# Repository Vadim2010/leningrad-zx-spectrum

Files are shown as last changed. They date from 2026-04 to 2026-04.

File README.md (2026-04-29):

# ZX Spectrum "Leningrad" Clone  
### Educational & Configurable Hardware Platform

---

## Overview

This repository is dedicated to the legendary **ZX Spectrum "Leningrad"**, one of the most widespread Soviet clones of the original [ZX Spectrum](https://en.wikipedia.org/wiki/ZX_Spectrum).

The project contains:
- The **original schematic** of the first "Leningrad" revision  
- A **modified, configurable version** of the board designed as an educational platform  

The goal is not just preservation, but **understanding** - how the machine works, why certain issues occur, and how historical fixes evolved.

---

## 🖼️ Hardware Preview

### Bare PCB

<p align="center">
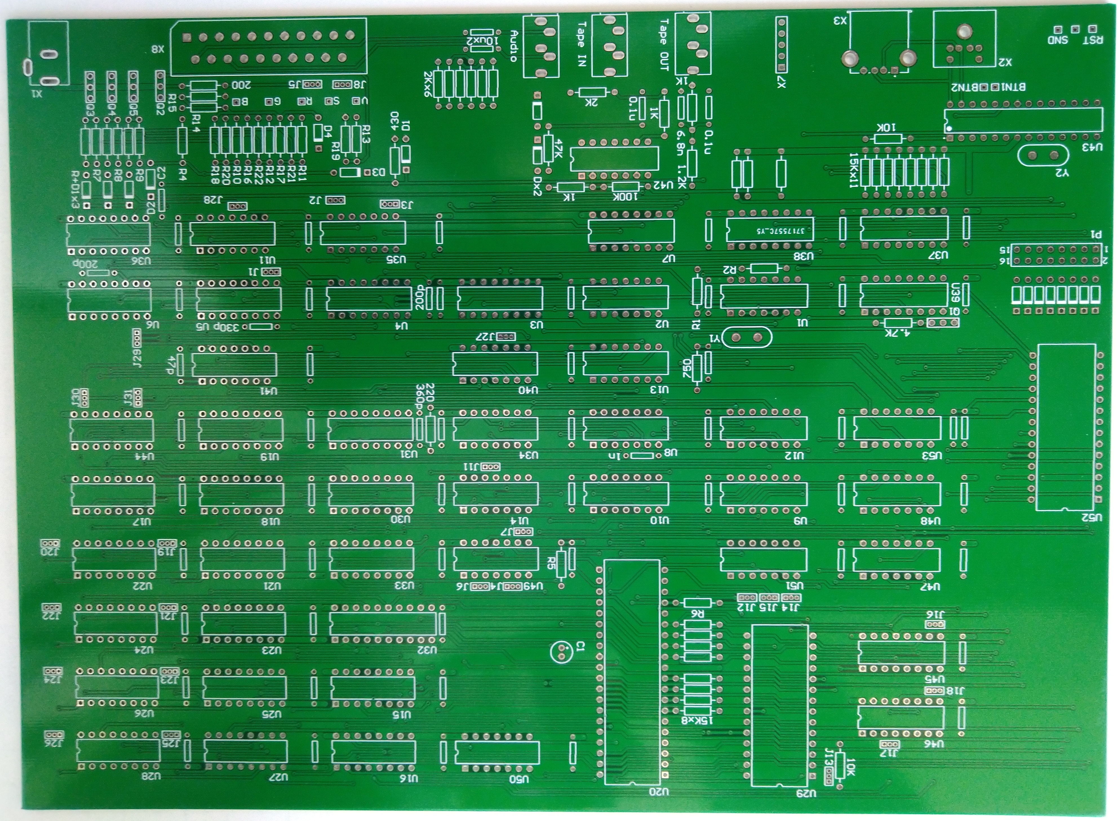
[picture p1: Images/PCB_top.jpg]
PCB top
  
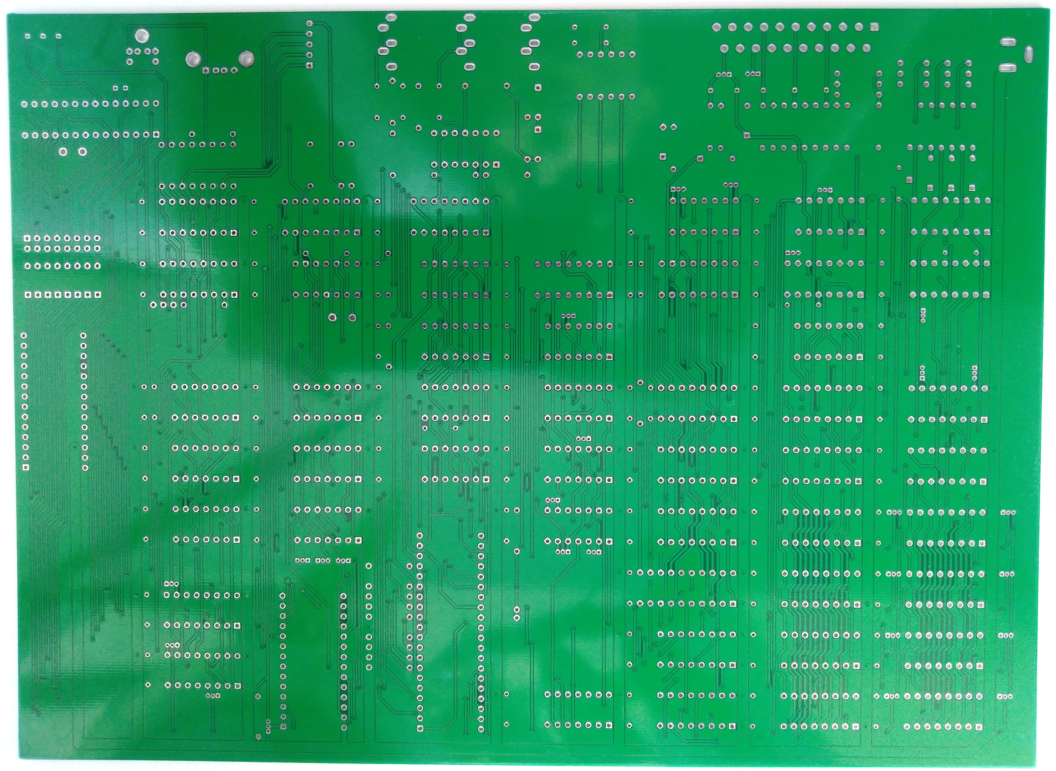
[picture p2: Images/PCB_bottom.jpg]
PCB bottom
  
</p>

### Assembled Board

<p align="center">
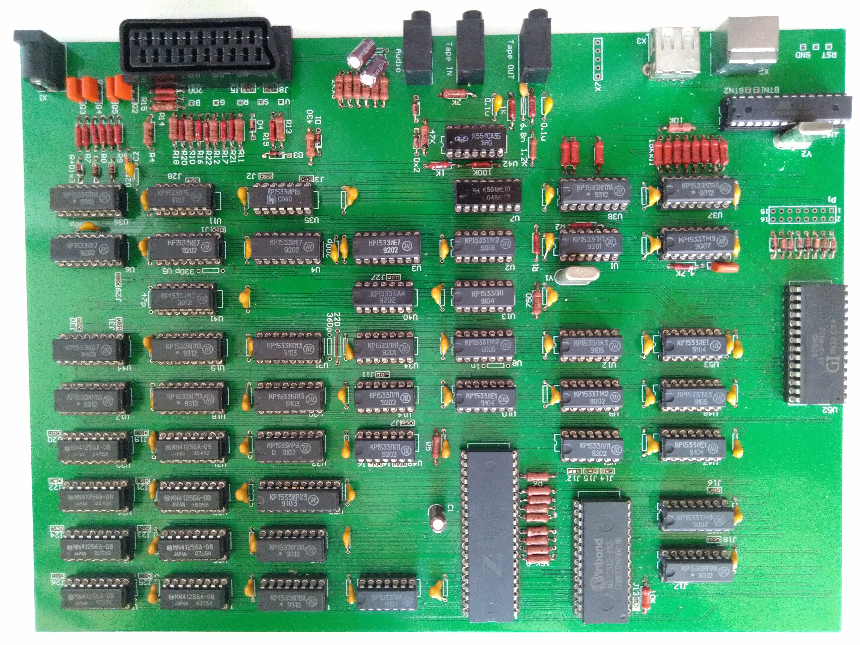
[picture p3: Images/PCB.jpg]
Assembled board
  
</p>

---

## A Brief History

The original [ZX Spectrum](https://en.wikipedia.org/wiki/ZX_Spectrum) was developed in the early 1980s by [Sir Clive Sinclair](https://en.wikipedia.org/wiki/Clive_Sinclair) and his company [Sinclair Research](https://en.wikipedia.org/wiki/Sinclair_Research). It became one of the most influential home computers of its time, shaping an entire generation of developers and enthusiasts.

Due to limited availability of Western hardware in many countries — especially in the USSR and Eastern Europe — a wide ecosystem of **unofficial clones** emerged. These ranged from near-identical reproductions to heavily modified designs adapted to locally available components.

Among them, the **"Leningrad"** clone became one of the most popular due to its:
- Relative simplicity  
- Component accessibility  
- Reliability (for its time)  

This repository pays respect to the original creators, the community that kept the platform alive, and everyone who contributed improvements over the decades.

---

## Project Goals

- Preserve the **original Leningrad schematic**
- Provide a **modernized, flexible board design**
- Enable **hands-on learning** of hardware behavior
- Demonstrate **real-world faults and fixes**
- Avoid destructive modifications (no cutting traces or solder hacks)

---

## Educational Concept

The modified board introduces a **jumper-based configuration system**.

By changing jumper positions, you can:

- Recreate the **original unmodified board**
- Apply **selected historical fixes**
- Mix different modifications
- Intentionally reproduce known hardware issues

This allows you to **observe cause and effect directly**, which is extremely valuable for learning.

---

## What You Can Study

- Timing issues and signal integrity  
- Memory contention behavior  
- Video signal stability  
- Bus conflicts and decoding quirks  

All of these can be observed:
- On a **TV/display output**
- With an **oscilloscope** (recommended for deeper analysis)

---

## Repository Structure

```
leningrad-zx-spectrum/
  ├── Leningrad/
  └── Leningrad_mod/
```

Leningrad       - Original Leningrad schematic and PCB (Altium)
Leningrad_mod   - Configurable board design (Altium)

---

## Hardware Features (Modified Version)

- Jumper-selectable logic paths  
- Support for multiple known fixes  
- Non-destructive experimentation  
- Designed for repeatable testing scenarios  

---

## Example Use Cases

- Compare **original vs fixed video timing**
- Demonstrate **typical hardware faults**
- Teach **digital electronics fundamentals**
- Explore **historical engineering decisions**

---

## ⚙️ Jumper Configuration Matrix

This board uses a fully jumper-based configuration system, allowing reconstruction of multiple hardware variants of the **ZX Spectrum "Leningrad"** architecture.

---

### ⏱ System Clock (Quartz Configuration)

| Quartz MHz | J1  | J2  | J3  |
|---|-----|-----|-----|
| 12.5 | 1-2 | 1-2 | 1-2 |
| 13.0 | 2-3 | 1-2 | 1-2 |
| 13.5 | 1-2 | 2-3 | 1-2 |
| 14.0 | 2-3 | 2-3 | 1-2 |
| 14.5 | 1-2 | 1-2 | 2-3 |
| 15.0 | 2-3 | 1-2 | 2-3 |
| 15.5 | 1-2 | 2-3 | 2-3 |
| 16.0 | 2-3 | 2-3 | 2-3 |

---

### 🧠 RAM Configuration

| Mode | J4  | J6  | J7  | J12–J26 |
|---|-----|-----|-----|---|
| 48K  | 1-2 | 1-2 | 1-2 | 1-2 |
| 128K | 2-3 | 2-3 | 2-3 | 2-3 |
| 256K | 2-3 | 2-3 | 1-2 | 2-3 |

> Enables switching between different memory architectures without PCB modification.

---

### 🎨 Video Output Mode

| Mode | J5  | J8  |
|---|-----|-----|
| RGB | 1-2 | 1-2 |
| Composite | 2-3 | 2-3 |

---

### 🔧 Logic IC Configuration

| IC Type | J11 |
|---|-----|
| SN74ALS373N | 1-2 |
| SN74ALS374N | 2-3 |

---

### 📺 Video Signal Enhancements

| Mode | J27–J30 |
|---|---|
| Leningrad | 1-2 |
|  Improve  | 2-3 |

---

### ⚡ Interrupt Handling

| Mode | J31 |
|---|-----|
| Leningrad | 1-2 |
|  Improve  | 2-3 |

---

## 🧪 Design Philosophy

This system is designed for **non-destructive hardware experimentation**:

- No trace cutting required  
- No permanent modifications  
- Full restoration of original behavior possible  

Simply change jumper positions to switch between configurations.

---

## Acknowledgements

Special thanks to:
- Sir Clive Sinclair for the original concept  
- Sinclair Research for the ZX Spectrum platform  
- The global retro computing community  
- Contributors who developed and documented hardware fixes over the years  

---

## Contributing

Contributions are welcome:
- Additional fixes  
- Measurements and oscilloscope captures  
- Documentation improvements  
- Historical research  

---

## Final Notes

This project is as much about **history** as it is about **engineering**.

It’s a way to explore how constraints, creativity, and community-driven innovation shaped one of the most iconic 8-bit ecosystems.

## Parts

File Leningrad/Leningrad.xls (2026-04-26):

Designator | LibRef | Quantity | Comment
ICs
U1, U34 | SN74LS04N | 2 | Orig K555LN1
U2, U8, U9 | SN74LS74N | 3 | Orig K555TM2
U3, U4, U5, U6 | SN74LS193N | 4 | Orig K555IE7
U7 | MC14520A | HEF4520B | CD4520B | 1 | Orig K561IE10
U10 | SN74LS02N | 1 | Orig K555LE1
U11 | SN74LS86N | 1 | Orig K555LP5
U12 | SN74LS00N | 1 | Orig K555LA3
U13 | SN74LS08N | 1 | Orig K555LI1
U14 | SN74LS32N | 1 | Orig K555LL1
U15, U16, U17, U18, U19, U36, U37, U38 | SN74LS257N | 8 | Orig K555KP11
U20 | Z84C0010PEC | 1 | Z80
U21, U22, U23, U24, U25, U26, U27, U28 | MK4164 | TMM4164 | MCM6664 | 8 | Orig K565RU5G
U29, U41 | 2764 | СМ7764 | M2764A | 2 | Orig K573RF4 | K573RF6
U30, U31 | SN74LS298N | 2 | Orig K555KP13
U32 | SN74LS373N | 1 | Orig K555IR22
U33 | SN74LS165N | 1 | Orig K555IR9
U35 | SN74LS295N | 1 | Orig K555IR16
U39 | SN74LS174N | 1 | Orig K555ТМ9
U40 | SN74LS10N | 1 | Orig K555LA4
Resistors
R1, R3, R16 | 430 | 3
R2, R14 | 750 | 2
R4 - R6, R26, RKL0 - RKL4 | 10k | 16
R7 - R9, RD1 - RD3 | 680 | 6
R10 - R13 | 75 | 4
R15, R17, R25, RDV0 - RDV4 | 1k | 8
R18 | 2k | 1
R19 - R22 | 200 | 4
R23 | 4.7k | 1
R24 | 1.5k | 1
Capacitors
C1 | 10uF 6.3V | 10V | 2
C2 | 33nF | 3
C3 - C18 | 0.1uF | 16* | decoupling capacitors
Diodes
D1 - D4, RD1 - RD3 | 1N4148 | 7
Transistors
T1, T2 | BC547 | BC548 | 2N2222 | 2SC9014 | 5
T2 |  | 1 | Orig 1NT251

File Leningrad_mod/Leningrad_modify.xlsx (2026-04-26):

Designator | LibRef | Quantity | Comment
ICs
U1, U34 | SN74AALS04N | 2 | Orig KR1533LN1
U2, U8, U9, U41 | SN74ALS74N | 4 | Orig KR1533TM2
U3, U4, U5, U6 | SN74ALS193N | 4 | Orig KR1533IE7
U7 | MC14520A | HEF4520B | CD4520B | 1 | Orig K561IE10
U10, U47, U53 | SN74ALS02N | 3 | Orig KR1533LE1
U11 | SN74ALS86N | 1 | Orig KR1533LP5
U12, U48 | SN74ALS00N | 2 | Orig KR1533LA3
U13, U50 | SN74ALS08N | 2 | Orig KR1533LI1
U14, U49, U51 | SN74ALS32N | 3 | Orig KR1533LL1
U15-U19, U36-U38, U46 | SN74ALS257N | 9 | Orig KR1533KP11
U20 | Z84C0010PEC | 1 | Z80
U21-U28 | MN41256A-08 | 8
U29 | M27C512-10B1 | W27C512 | 1
U30, U31 | SN74ALS298N | 2 | Orig KR1533KP13
U32 | SN74ALS373N* | 1 | Orig KR1533IR22
U33 | SN74ALS165N | 1 | Orig KR1533IR9
U35 | SN74ALS295N | 1 | Orig KR1533IR16
U39, U45 | SN74ALS174N | 2 | Orig KR1533ТМ9
U40 | SN74ALS10N | 1 | Orig KR1533LA4
U42 | LM311 | 1 | Orig K554SA3
U43 | ATmega168A-PU | 1
U44 | SN74ALS138N | 1 | Orig KR1533ID7
U52 | AY-3-8912 | 1
Resistors
R1, R2, R16 | 470 | 3
R3, R14 | 750 | 2
R4-R6, R52, R56 | 10k | 5
R7-R9, R53-R55 | 680 | 6
R10-R13 | 75 | 4
R15, R17, R32, R45, R50 | 1k | 5
R18, R46, R57-R62 | 2k | 8
R19-R22, R63 | 200 | 5
R23 | 430 | 1
R24 | 4.7k | 1
R25 | 220 | 1
R26-R30, R33-R44, R47, R48 | 15k | 19
R31 | 1.2k | 1
R49 | 47k | 1
R51 | 100k | 1
Capacitors
C1, C52, C53 | 10u 6.3V | 10V | 3
C2 | 33n | 1
C3-C9, C13-C22, C25-C44, C47, C48, C51, C54-C62 | 0.1u | 49* | decoupling capacitors
C10, C11 | 200p* | 2 | 200-220p
C12 | 330p | 1
C23 | 6.8n | 1
C24, C46 | 0.1u | 2
C45 | 1n* | 1 | 1n-4.7n
C49 | 47p | 1
C50 | 360p | 1
Diodes
D1-D17 | 1N4148 | 17*
Transistors
Q1-Q5 | BC547 | BC548 | 2N2222 | 2SC9014 | 5
XOs
Y1 | 14MHz | 1
Y2 | 24MHz | 1

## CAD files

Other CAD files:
Leningrad/len.dxf

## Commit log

2026-04-26 Initial commit: Altium project files
    [Audio.SchDoc, AudioAY.SchDoc, CPU.SchDoc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]
2026-04-29 Add board images
